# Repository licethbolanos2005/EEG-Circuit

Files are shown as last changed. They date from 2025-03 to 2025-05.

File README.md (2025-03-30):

# Implementación de un Electroencefalógrafo para Síntesis Musical

Este proyecto se centra en el diseño de un electroencefalograma (EEG) con énfasis en interfaz cerebro-computadora (BCI). Su objetivo es proporcionar a personas con discapacidad motora una herramienta adicional de interacción mediante un aplicativo de computadora que recopila señales cerebrales a través de electrodos ubicados en una bandana.

## Estructura del repositorio

Este repositorio contiene las siguientes carpetas:

- **Schematic**: Contiene las diferentes versiones del esquemático del proyecto, diseñadas con AutoDesk Eagle. Cada versión refleja el proceso de desarrollo y los cambios implementados con el tiempo.
- **libraries**: Incluye todas las librerías utilizadas para la creación del esquemático.
- **Board**: Contiene las diferentes versiones de los diseños de la placa desarrollados para el proyecto, reflejando las modificaciones y mejoras a lo largo del tiempo.

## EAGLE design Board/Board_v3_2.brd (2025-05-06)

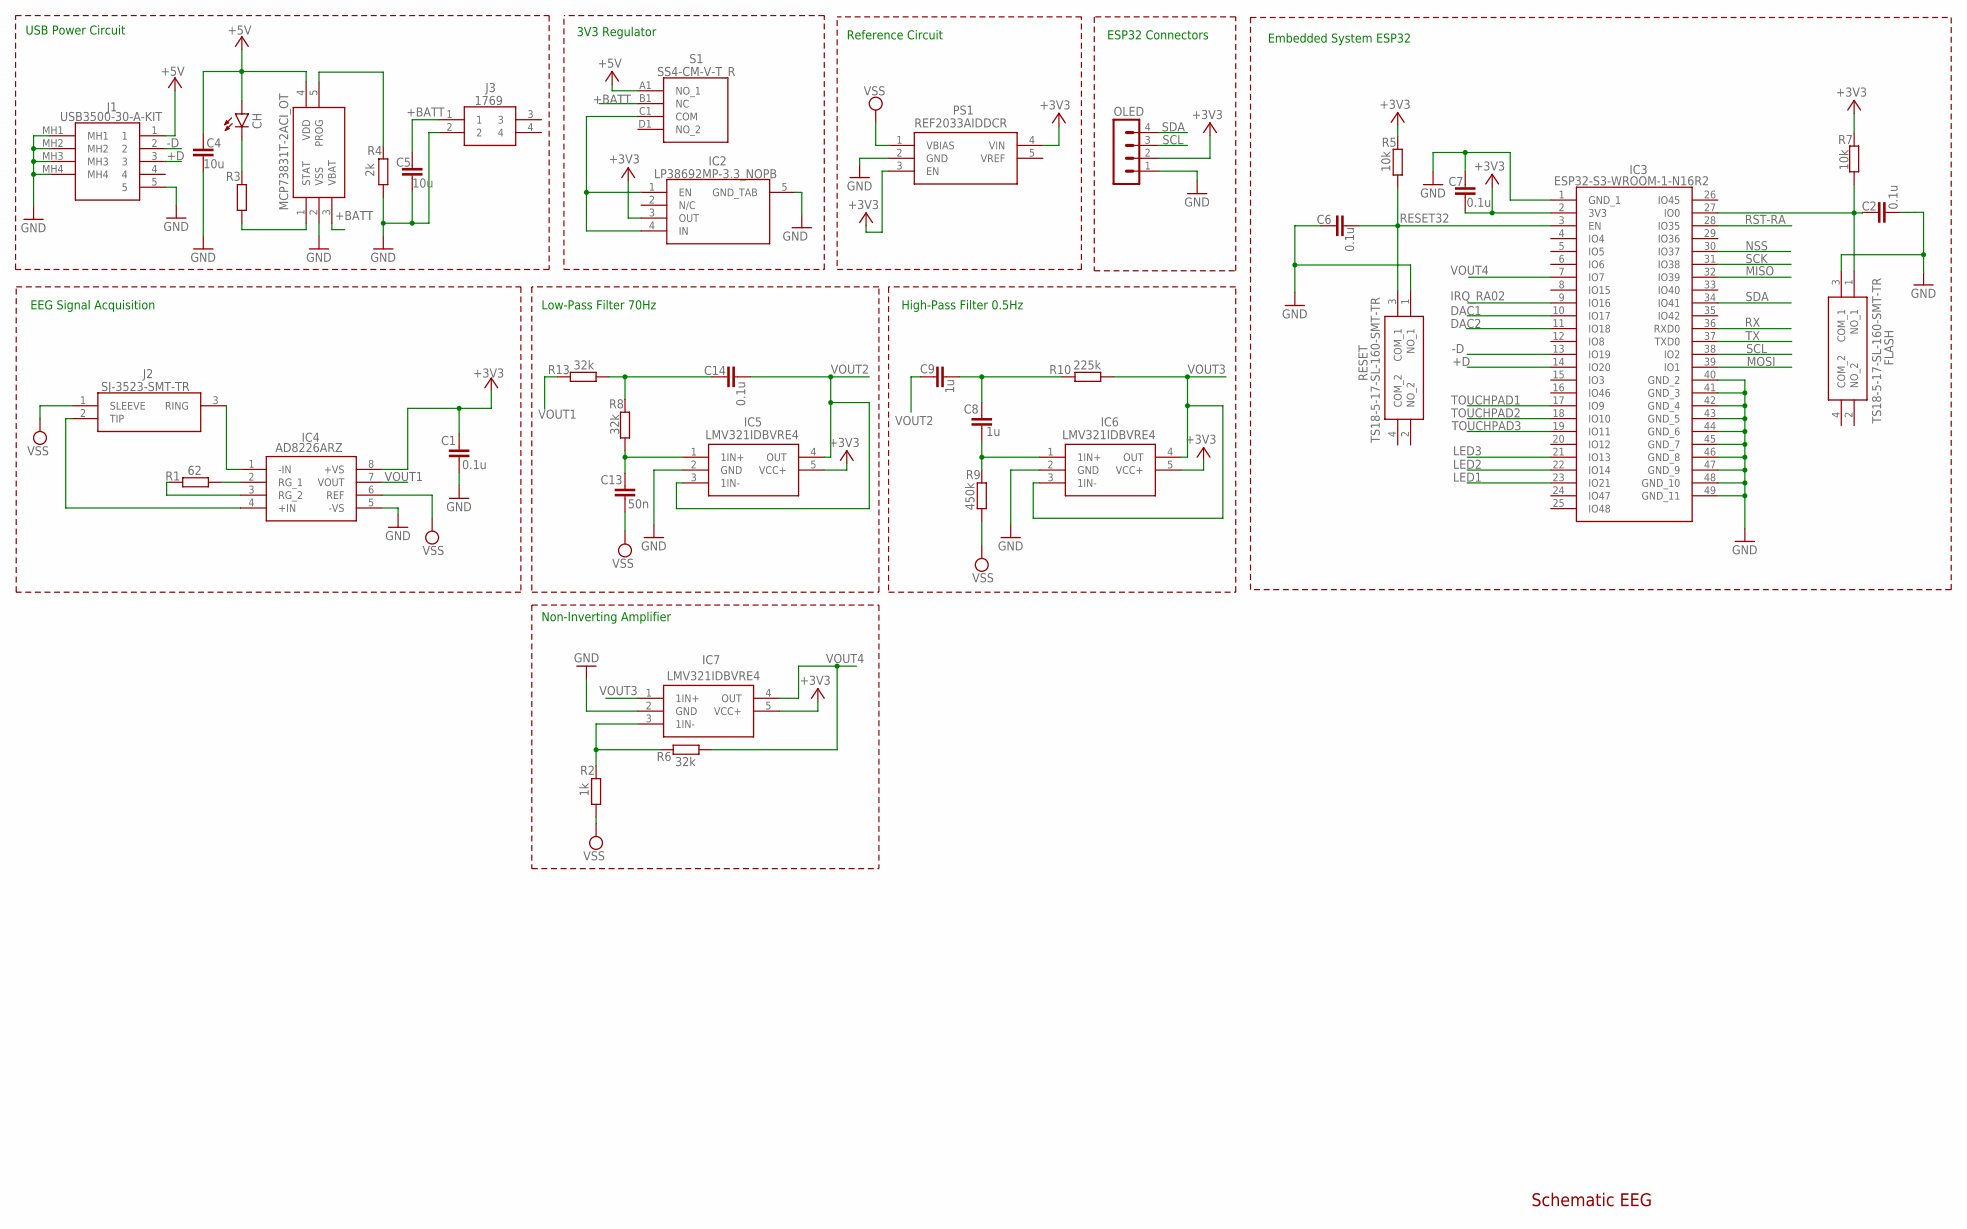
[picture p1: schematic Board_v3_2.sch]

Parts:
C1, C2, C6, C7, C14: 0.1u; C0805
C4, C5: 10u; C0805
C8, C9: 1u; C0805
C13: 50n; C0805
CH: LEDCHIP-LED0805; CHIP-LED0805
FLASH: TS18-5-17-SL-160-SMT-TR; TS18517SL160SMTTR
IC1: MCP73831T-2ACI_OT; SOT95P270X145-5N
IC2: LP38692MP-3.3_NOPB; SOT150P700X180-5N
IC3: ESP32-S3-WROOM-1-N16R2; ESP32S3WROOM1N16R2
IC4: AD8226ARZ; SOIC127P600X175-8N
IC5, IC6, IC7: LMV321IDBVRE4; SOT95P280X145-5N
J1: USB3500-30-A-KIT; USB350030AKIT
J2: SJ-3523-SMT-TR; SJ3523SMTTR
J3: 1769
OLED: MA04-1
PS1: REF2033AIDDCR; SOT95P280X110-5N
R1: 62; R0805
R2: 1k; R0805
R3: 220; R0805
R4: 2k; R0805
R5, R7: 10k; R0805
R6, R8, R13: 32k; R0805
R9: 450k; R0805
R10: 225k; R0805
RESET: TS18-5-17-SL-160-SMT-TR; TS18517SL160SMTTR
S1: SS4-CM-V-T_R; SS4CMVTR

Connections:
+3V3: C1.1, C7.2, IC2.3 (OUT), IC3.2 (3V3), IC4.8 (+VS), IC5.5 (VCC+), IC6.5 (VCC+), IC7.5 (VCC+), OLED.2, PS1.3 (EN), PS1.4 (VIN), R5.2, R7.2
+5V: C4.2, CH.A, IC1.4 (VDD), J1.1, S1.A1 (NO_1)
+BATT: C5.2, IC1.3 (VBAT), J3.1, S1.B1 (NC)
+D: IC3.14 (IO20), J1.3
-D: IC3.13 (IO19), J1.2
DAC1: IC3.10 (IO17)
DAC2: IC3.11 (IO18)
GND: C1.2, C2.2, C4.1, C5.1, C6.1, C7.1, FLASH.3 (COM_1), IC1.2 (VSS), IC2.5 (GND_TAB), IC3.1 (GND_1), IC3.40 (GND_2), IC3.41 (GND_3), IC3.42 (GND_4), IC3.43 (GND_5), IC3.44 (GND_6), IC3.45 (GND_7), IC3.46 (GND_8), IC3.47 (GND_9), IC3.48 (GND_10), IC3.49 (GND_11), IC4.5 (-VS), IC5.2 (GND), IC6.2 (GND), IC7.2 (GND), J1.5, J1.MH1, J1.MH2, J1.MH3, J1.MH4, J3.2, OLED.1, PS1.2 (GND), R4.1, RESET.1 (NO_1)
IRQ_RA02: IC3.9 (IO16)
LED1: IC3.23 (IO21)
LED2: IC3.22 (IO14)
LED3: IC3.21 (IO13)
MISO: IC3.32 (IO39)
MOSI: IC3.39 (IO1)
unnamed: IC4.2 (RG_1), R1.2
unnamed: IC4.3 (RG_2), R1.1
unnamed: IC4.1 (-IN), J2.3 (RING)
unnamed: IC4.4 (+IN), J2.2 (TIP)
unnamed: C8.2, IC6.1 (1IN+), R9.2
unnamed: IC1.1 (STAT), R3.1
unnamed: IC1.5 (PROG), R4.2
unnamed: CH.C, R3.2
unnamed: C8.1, C9.2, R10.1
unnamed: C2.1, FLASH.1 (NO_1), IC3.27 (IO0), R7.1
unnamed: C13.1, IC5.1 (1IN+), R8.1
unnamed: IC2.1 (EN), IC2.4 (IN), S1.C1 (COM)
unnamed: IC7.3 (1IN-), R2.2, R6.2
unnamed: C14.1, R8.2, R13.2
NSS: IC3.30 (IO37)
RESET32: C6.2, IC3.3 (EN), R5.1, RESET.3 (COM_1)
RST-RA: IC3.28 (IO35)
RX: IC3.36 (RXD0)
SCK: IC3.31 (IO38)
SCL: IC3.38 (IO2), OLED.3
SDA: IC3.34 (IO41), OLED.4
TOUCHPAD1: IC3.17 (IO9)
TOUCHPAD2: IC3.18 (IO10)
TOUCHPAD3: IC3.19 (IO11)
TX: IC3.37 (TXD0)
VOUT1: IC4.7 (VOUT), R13.1
VOUT2: C9.1, C14.2, IC5.3 (1IN-), IC5.4 (OUT)
VOUT3: IC6.3 (1IN-), IC6.4 (OUT), IC7.1 (1IN+), R10.2
VOUT4: IC3.7 (IO7), IC7.4 (OUT), R6.1
VSS: C13.2, IC4.6 (REF), J2.1 (SLEEVE), PS1.1 (VBIAS), R2.1, R9.1

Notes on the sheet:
Schematic EEG
USB Power Circuit
3V3 Regulator
Reference Circuit
Embedded System ESP32
ESP32 Connectors
Low-Pass Filter 70Hz
High-Pass Filter 0.5Hz
EEG Signal Acquisition
Non-Inverting Amplifier

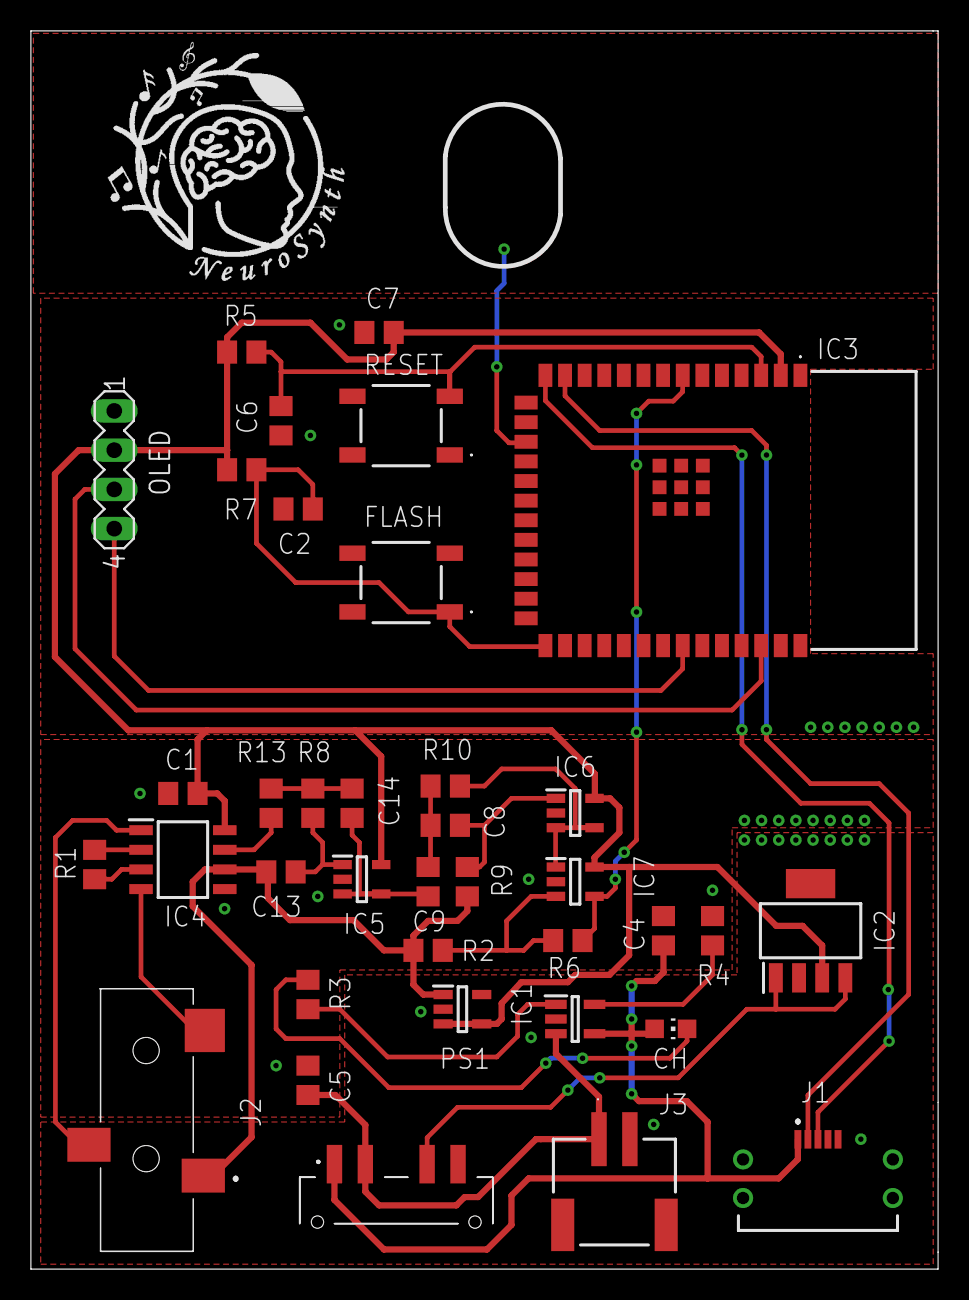
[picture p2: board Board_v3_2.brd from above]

Board: 2 copper layers, 58.7 x 80.2 mm, 37 parts (0 on the bottom side), 28 nets.

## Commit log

2025-03-23 El primer diseño de esquemático realizado por todos, con las correcciones del docente
    [Schematic_v1_0.sch]
2025-03-24 Se Agregro el bloque de carga de batería
    [Schematic_v2_0.sch]
2025-03-24 Agregué librerías usadas en el primer esquemático
2025-03-24 Primer esquemático realizado por todos
    [Schematic_v1_0.sch]
2025-03-24 Agregué librerías usadas en Schematic_v1_0.sch
2025-03-24 Agregué el bloque de carga de batería
    [Schematic_v2_0.sch]
2025-03-24 Agregué las librerías usadas en Schematic_v2_0.sch
2025-03-24 Agregué las librerías usadas en Schematic_v2_1
2025-03-24 Agregué el bloque de sistemas embebido
    [Schematic_v2_1.sch]
2025-03-27 Librería Regulador de Voltaje
2025-03-27 Librería Voltaje de Referencia (Tierra Común)
2025-03-27 Agregué las librerías usadas en Schematic_v2_2.sch
2025-03-27 Agregue los bloques: Regulador 3V3 y Voltaje Referencia
    Así mismo realicé correcciones en la visualización de los bloques y conexiones de los bloques pasados.
    [Schematic_v2_2.sch]
2025-03-28 Agregué las librerías usadas en Schematic_v2_3.sch
2025-03-28 Agregué Los bloques: Conectores de ESP32 y Filtros
    [Schematic_v2_3.sch]
2025-03-29 Agregué la librería usada en Schematic_v3_0.sch
2025-03-29 Corregí los bloques de Regulador 3v3 y Voltaje Referencia
    [Schematic_v3_0.sch]
2025-03-29 Agregué las librerías usadas en Schematic_v3_1.sch
2025-03-29 Add files via upload
    Corregí los bloques de Adquisición de señales, Conectores de ESP32 y Filtros
    [Schematic_v3_1.sch]
2025-03-29 Corregí los bloques de Adquisición de señales, Conectores de ESP32 Y Filtros
    [Schematic_v3_1.sch]
2025-03-29 Corregí el bloque de carga de batería
    [Schematic_v3_2.sch]
2025-03-30 correji el bloque de sistema embebido
    [Schematic_v3_3.sch]
2025-03-30 agregue libreria usadas en Schematic_v3_3.sch
2025-03-30 Corregí el bloque del sistema Embebido
    [Schematic_v3_3.sch]
2025-03-30 Agregue librería usada en Schematic_v3_3.sch
2025-03-30 Corregi el bloque de carga de batería
    [Schematic_v3_4.sch]
2025-03-30 Agregué librería usada en Schematic_v3_2.sch
2025-04-04 Primer Diseño de PCB realizado
    [Board_v1_0.brd]
2025-04-05 Agregué el bloque de amplificador no inversor
    [Schematic_v3_5.sch]
2025-04-05 Primer diseño de la pcb
    [Schematic_v3_5.brd]
2025-04-05 Esquemático del proyecto
    [Schematic_v3_5.sch]
2025-04-05 Realicé el montaje de los componentes electrónicos en la PCB
    [Board_v1_0.brd, Board_v1_0.sch]
2025-04-06 Corregí el orden de los componentes y realicé pistas entre los componentes
    [Board_v1_2.brd, Board_v1_2.sch]
2025-04-06 Corregí el orden de los componentes y realicé pistas entre los componentes
    [Board_v1_1.brd, Board_v1_1.sch]
2025-04-06 Corregí tamaño de pistas y agregué las faltantes.
    [Board_v1_2.brd, Board_v1_2.sch]
2025-04-08 Corregí tamaño y ángulos rectos en las pistas, y cambié la organización de algunos componentes
    [Board_v1_3.brd, Board_v1_3.sch]
2025-04-13 Correcciones del profesor
    [Board_v1_4.brd, Board_v1_4.sch]
2025-04-22 Realicé los planos de tierra y corregí algunas conexiones
    [Board_v2_0.brd, Board_v2_0.sch]
2025-04-23 Agregué el touchpad y corregí algunas conexiones
    [Board_v2_1.brd, Board_v2_1.sch]
2025-04-24 Agregué el logo al diseño
    [Board_v2_2.brd, Board_v2_2.sch]
2025-04-25 Realicé revisión del diseño
    [Board_v2_3.brd, Board_v2_3.sch]
2025-04-25 Realicé revisión del diseño y deshabilité algunas capas
    [Board_v2_3.brd]
2025-04-25 Reemplacé la ESP32 por una que se encuentra disponible
    [Board_v2_4.brd, Board_v2_4.sch]
2025-04-25 Agregué la librería de la ESP32 que se encuentra disponible
2025-04-25 Agregué los valores de los componentes
    [Schematic_v4_0.sch]
2025-05-05 Organicé los nombres de los componentes y corregí conexión en el esquemático
    [Board_v3_0.brd, Board_v3_0.sch]
2025-05-05 Realicé una pista de una conexión faltante
    [Board_v3_1.brd, Board_v3_1.sch]
2025-05-06 Agregué un pad de tierra en una isla huérfana
    [Board_v3_2.brd, Board_v3_2.sch]
